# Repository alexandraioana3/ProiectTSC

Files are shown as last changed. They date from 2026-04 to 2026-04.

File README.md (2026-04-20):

==================================================
 PROIECT TSC 2026 - InkTime Smartwatch
==================================================
DINU ALEXANDRA - IOANA 332CC

1. DIAGRAMA BLOC

se afla in Diagrama-bloc.png

--------------------------------------------------
2. BILL OF MATERIALS (BOM)
--------------------------------------------------

Componenta      : MCU
Model           : Nordic nRF52840
Cod JLC         : C227306
Datasheet       : https://infocenter.nordicsemi.com/pdf/nRF52840_PS_v1.7.pdf

Componenta      : Charger
Model           : TI BQ25180
Cod JLC         : C5162464
Datasheet       : https://www.ti.com/lit/ds/symlink/bq25180.pdf

Componenta      : Fuel Gauge
Model           : Maxim MAX17048
Cod JLC         : C224357
Datasheet       : https://datasheets.maximintegrated.com/en/ds/MAX17048-MAX17049.pdf

Componenta      : Accelerometer
Model           : Bosch BMA421
Cod JLC         : C281864
Datasheet       : https://www.mouser.com/datasheet/2/783/bst-bma421-ds000-1509549.pdf

Componenta      : Haptic Driver
Model           : TI DRV2605L
Cod JLC         : C137152
Datasheet       : https://www.ti.com/lit/ds/symlink/drv2605l.pdf

Componenta      : Regulator
Model           : Richtek RT6160
Cod JLC         : C2892336
Datasheet       : https://www.richtek.com/assets/product_pdf/RT6160A/DS6160A-02.pdf

--------------------------------------------------
3. DESCRIERE FUNCTIONALITATE HARDWARE
--------------------------------------------------

[Sistemul de Putere]

- Incarcarea bateriei Li-Po se face prin BQ25180
- Monitorizare curent si temperatura integrata
- RT6160 stabilizeaza tensiunea la 3.3V
- Functionare posibila pana la ~2.8V baterie

[Senzori si Interfete]

- MAX17048:
  * Citire procent baterie prin I2C
  * Fara rezistenta externa de masura

- BMA421:
  * Detectie miscare
  * Step counting
  * Tilt-to-wake

- DRV2605L:
  * Control motor vibratii (ERM/LRA)
  * Efecte haptice integrate

- E-Paper Display:
  * Consum zero in stare statica
  * Control prin SPI

--------------------------------------------------
4. ALOCARE PINI nRF52840
--------------------------------------------------

USB D+ / D-  | USB Data     | USB-C (J5)
             |              | Pini dedicati pentru comunicatia USB nativa

P0.06        | I2C SDA      | Senzori / PMIC
             |              | Magistrala date (BMA421, MAX17048, BQ25180)

P0.07        | I2C SCL      | Senzori / PMIC
             |              | Magistrala clock pentru comunicatia I2C

P0.02        | SPI SCK      | E-Paper Display
             |              | Semnal de ceas pentru magistrala SPI

P0.03        | SPI MOSI     | E-Paper Display
             |              | Transmisie date imagine catre ecran

P0.05        | SPI CS       | E-Paper Display
             |              | Chip Select - activeaza comunicarea cu ecranul

P0.15        | EPD DC       | E-Paper Display
             |              | Data/Command control pentru driverul de ecran

P0.16        | EPD RST      | E-Paper Display
             |              | Reset hardware pentru panoul E-Paper

P0.17        | EPD BUSY     | E-Paper Display
             |              | Feedback de la ecran (procesare imagine)

P0.12        | HAPTIC EN    | DRV2605L
             |              | Activare / Trigger pentru driverul haptic

P0.11        | PMIC INT     | BQ25180
             |              | Intrerupere de la charger

P0.10        | ALERT        | MAX17048
             |              | Alerta baterie (ex: nivel critic)

P0.08        | IMU INT1     | BMA421
             |              | Intrerupere accelerometru (tap/tilt)

P1.08        | IMU INT2     | BMA421
             |              | Intrerupere secundara (low power)

P1.06        | BUTTON       | SW_UP
             |              | Buton navigare sus

P1.04        | BUTTON       | SW_DN
             |              | Buton navigare jos

P0.18        | RESET        | Debug Port
             |              | Reset hardware extern

SWDIO        | Debug Data   | TC2030 (J2)
             |              | Linie date programare

SWDCLK       | Debug Clock  | TC2030 (J2)
             |              | Linie ceas programare

P0.00 / 0.01 | XL1 / XL2    | Cristal 32kHz
             |              | Oscilator low power / RTC

XC1 / XC2    | HF Crystal   | Cristal 32MHz
             |              | Frecventa principala + BLE

VBUS         | Power Sense  | USB VBUS
             |              | Detectie 5V USB

VDDH         | High Voltage | 3.3V VCC
             |              | Alimentare principala

--------------------------------------------------
5. DESIGN LOG SI DECIZII
--------------------------------------------------

[Status: Finalizare Partiala]

- Overlap Errors (#16):
  * 65 erori acceptate
  * Cauza: densitate mare aQFN + PCB 2 straturi
  * Solutie viitoare: PCB 4 straturi

- Airwires (#15):
  * 16 conexiuni ramase
  * Nu afecteaza functionarea de baza
  * Evitare scurtcircuite in zone critice

- Antena RF:
  * Ground stitching aplicat
  * Keep-out respectat sub antena

- Vizualizare 3D:
  * PCB validat mecanic (1.0mm grosime)
  * Fara modele 3D componente

--------------------------------------------------
6. FISIERE DE FABRICATIE
--------------------------------------------------

Folder: /Manufacturing

Contine:

- Gerber Files (pentru productie PCB)
- BOM (lista componente)
- Pick and Place (asamblare SMT)

==================================================

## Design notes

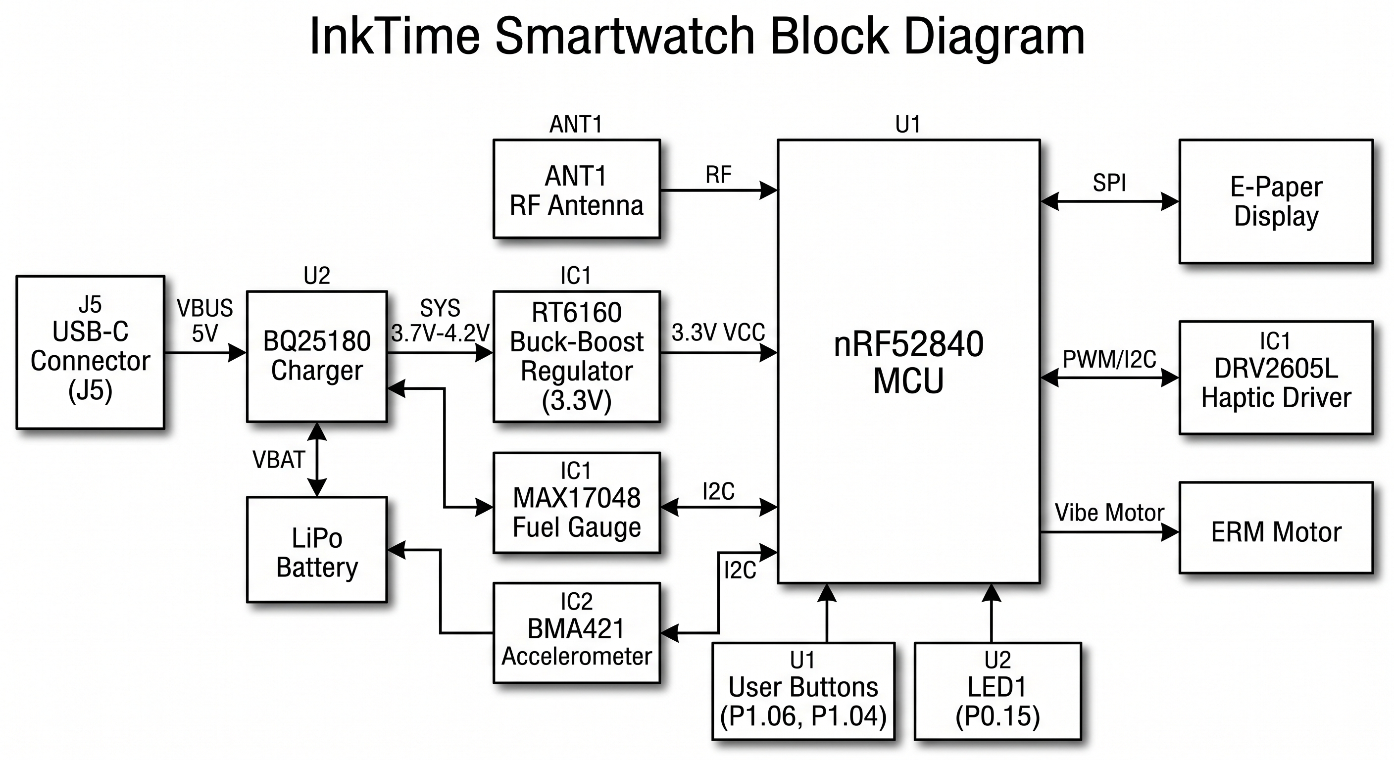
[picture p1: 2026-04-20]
Diagrama-Bloc.png

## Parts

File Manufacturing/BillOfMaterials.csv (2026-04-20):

Componenta | Producator/Model | Cod JLC Parts | Link Datasheet
MCU | Nordic nRF52840 | C227306 | https://infocenter.nordicsemi.com/pdf/nRF52840_PS_v1.7.pdf
Charger | TI BQ25180 | C5162464 | https://www.ti.com/lit/ds/symlink/bq25180.pdf
Fuel Gauge | Maxim MAX17048 | C224357 | https://datasheets.maximintegrated.com/en/ds/MAX17048-MAX17049.pdf
Accelerometer | Bosch BMA421 | C281864 | https://www.mouser.com/datasheet/2/783/bst-bma421-ds000-1509549.pdf
Haptic Driver | TI DRV2605L | C137152 | https://www.ti.com/lit/ds/symlink/drv2605l.pdf
Regulator | Richtek RT6160 | C2892336 | https://www.richtek.com/assets/product_pdf/RT6160A/DS6160A-02.pdf

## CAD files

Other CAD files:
Manufacturing/pcb-3d.f3d

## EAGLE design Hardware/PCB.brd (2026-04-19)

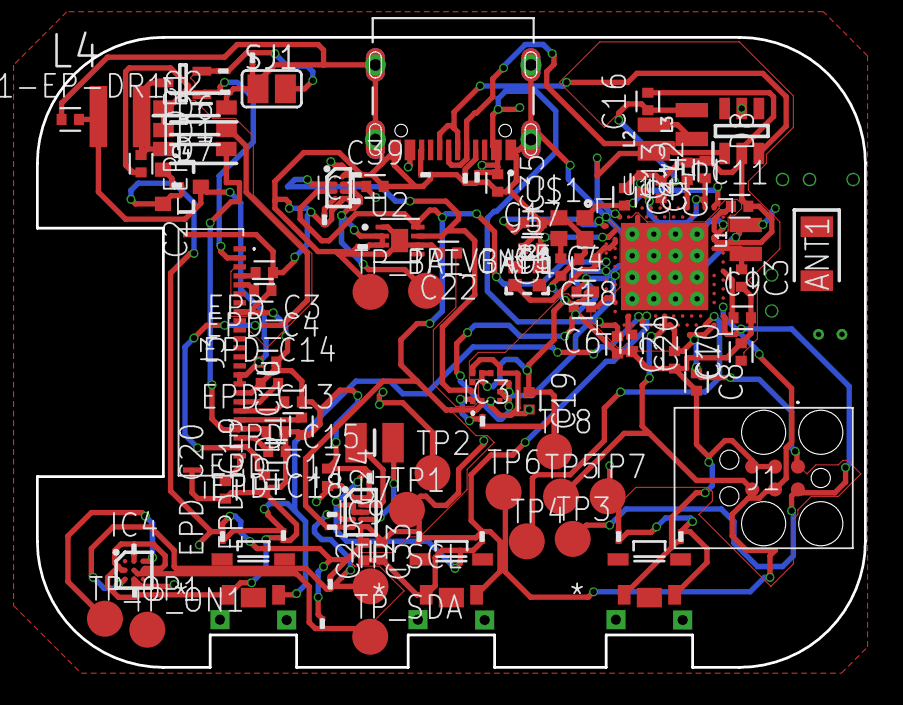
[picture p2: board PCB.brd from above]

Board: 4 copper layers, 46.0 x 35.0 mm, 105 parts (0 on the bottom side), 68 nets.

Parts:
ANT1: 2450AT18B100E; 2450AT18B100E_ANTC3216X140N
C1, C2, C17, C18: 12pF; CAPC1005X60
C1-EP-DR1, C24, C39: 10uF; CAPC1005X60
C2-EP-DR1: 4.7uF/25V; CAPC1005X60
C3, C4: 1pF; CAPC1005X60
C5, C7, C8, C12, C19: 100nF; CAPC1005X60
C6, C14, C20, C21: 4.7μF; CAPC1005X60
C9: 820pF N.C.; CAPC1005X60
C10, C13, C22: N.C.; CAPC1005X60
C11: 100pF; CAPC1005X60
C15: 1.0μF; CAPC1005X60
C16: 47nF; CAPC1005X60
C23, C26, C28, C36: 0.1uF; GRM011R60J152KE01L_1_0201
C25, C33: 22uF; CAPC1005X60
C35: 4.7uF; CAPC1005X60
C37, C38, C40, C41, C44, C45: 1uF; GRM011R60J152KE01L_1_0201
D1, D6, D7: MBR0530; ESP32_C6_LIBRARY_5_SOD3716X135N
D8: USBLC6-2SC6Y; ESP32_C6_LIBRARY_3_SOT95P280X145-6N
EPD_C3, EPD_C4, EPD_C14, EPD_C15, EPD_C16, EPD_C17, EPD_C18, EPD_C19, EPD_C20: 1uF/50V; CAPC1005X60
EPD_C13: 0.1uF/50V; CAPC1005X60
IC1: BQ25180YBGR; BQ25180YBGR_BGA8C40P2X4_100X155X50
IC3: BMA421; BMA423_BMA423
IC4: DRV2605YZFR; DRV2605YZFR_BGA9C50P3X3_144X144X62
IC9: RT6160AWSC; RT6160AWSC_BGA15C40P3X5_140X230X60
J1: TC2030-IDC_TC2030-IDC; TC2030-IDC_TC2030IDC
J3: 503480-2400; 503480-2400_5034802400
J5: KH-TYPE-C-16P; KH-TYPE-C-16P_KINGHELM_KH-TYPE-C-16P
L1: 3.9nH; 0805-WIDE
L2: 10μH; 0805-WIDE
L3: 15nH; 0805-WIDE
L4: 68uH; XFL4020
L7: FTC252012SR47MBCA; MLP2016SR47MT0S1_INDC2016X100N
Q2: SI1308EDL-T1-GE3; ESP32_C6_LIBRARY_6_SOT65P210X110-3N
Q4: 20V/4.2A/52mΩ/1.4W; ESP32_C6_LIBRARY_4_ESP32_C6_LIBRARY_4_ESP32_C6_LIBRARY_4_ES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
R1, R6, R10: 10k; CPF0201D7K68C1_0201
R1_EP_DR1: 0.47; CPF0201D7K68C1_0201
R1_USB1, R2_USB1: 5K1; CPF0201D7K68C1_0201
R2, R3, R4: 0; CPF0201D7K68C1_0201
R2_EP_DR1, R9: 10K; CPF0201D7K68C1_0201
R17, R18: 3K3; CPF0201D7K68C1_0201
R_PWR_EPD1: 10K; CPF0201D7K68C1_0201
R_TYPE_SEL1: 2.2; CPF0201D7K68C1_0201
SJ1: 0; ESP32_C6_LIBRARY_7_JUMPER_SJ
SW_DN: 2025-10-22_07-23-44_LIBRARY_EVP-AKE31ASW_EVP-AKE3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; 2025-10-22_07-23-44_LIBRARY_SW_EVP-AKE31A_PAN
SW_ENT: 2025-10-22_07-23-44_LIBRARY_EVP-AKE31ASW_EVP-AKE3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; 2025-10-22_07-23-44_LIBRARY_SW_EVP-AKE31A_PAN
SW_UP: 2025-10-22_07-23-44_LIBRARY_EVP-AKE31ASW_EVP-AKE3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; 2025-10-22_07-23-44_LIBRARY_SW_EVP-AKE31A_PAN
TP1, TP2, TP3, TP4, TP5, TP6, TP7, TP8: HECTOR_WATCH_1_TPTP20R; HECTOR_WATCH_1_TP20R
TP_BAT_GND1: HECTOR_WATCH_1_TPTP20R; HECTOR_WATCH_1_TP20R
TP_ON1: HECTOR_WATCH_1_TPTP20R; HECTOR_WATCH_1_TP20R
TP_OP1: HECTOR_WATCH_1_TPTP20R; HECTOR_WATCH_1_TP20R
TP_SCL: HECTOR_WATCH_1_TPTP20R; HECTOR_WATCH_1_TP20R
TP_SDA: HECTOR_WATCH_1_TPTP20R; HECTOR_WATCH_1_TP20R
TP_VBAT1: HECTOR_WATCH_1_TPTP20R; HECTOR_WATCH_1_TP20R
U1: NRF52840_QF; NORDIC_NRF_4_AQFN50P700X700X85_HS-74N
U2: MAX17048G+T10; ESP32_C6_LIBRARY_SON50P200X200X80-9N
U$1: NORDIC_NRF_BT-XTAL_2016_N
X2: 32MHz; CRYSTAL-SMD-2.0X1.6MM

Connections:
3V3: C6.1, C7.1, C8.1, C12.1, C14.2, C19.2, C25.2, C33.1, C36.2, IC3.3, IC3.7, IC3.10, IC4.C2, IC9.E2, IC9.E3, J1.1, Q4.2, R1.2, R6.2, R10.2, R17.1, R18.1, R_PWR_EPD1.2, TP1.TP, TP7.TP, U1.P$A22, U1.P$AD14, U1.P$AD23, U1.P$B1, U1.P$W1, U1.P$Y2
3V3/1.7D2: C40.2, IC4.A2
ALERT: U1.P$J24, U2.5
D+: D8.4, U1.P$AD6
D-: D8.6, U1.P$AD4
DEC1: C5.2, U1.P$C1
DEC3: C11.1, U1.P$D23
DEC4_6: C10.1, C15.2, C16.1, L3.2, U1.P$B5, U1.P$E24
DN: D8.1, J5.A7, J5.B7
DP: D8.3, J5.A6, J5.B6
EPD_3V3: C1-EP-DR1.2, EPD_C13.2, J3.15, J3.16, L4.P$1, Q4.3
EPD_BUSY: J3.9, U1.P$AD12
EPD_CS: J3.12, U1.P$K2
EPD_DC: J3.11, U1.P$AD10
EPD_RST: J3.10, U1.P$AC11
GDR: J3.2, Q2.1, R2_EP_DR1.2
GND: C1.1, C1-EP-DR1.1, C2.1, C3.2, C4.2, C5.1, C6.2, C7.2, C8.2, C9.2, C10.2, C11.2, C12.2, C13.2, C14.1, C15.1, C16.2, C17.1, C18.2, C19.1, C20.2, C21.2, C22.2, C23.2, C24.1, C25.1, C26.1, C28.2, C33.2, C35.2, C36.1, C37.1, C38.1, C39.2, C40.1, C41.1, C44.1, C45.1, D6.1, D8.2, EPD_C3.1, EPD_C4.1, EPD_C13.1, EPD_C14.1, EPD_C15.1, EPD_C16.1, EPD_C17.1, EPD_C18.1, EPD_C19.1, EPD_C20.1, IC1.D2, IC3.8, IC3.9, IC4.B1, IC4.B3, IC9.B1, IC9.C1, IC9.C2, IC9.C3, J1.3, J1.5, J3.8, J3.17, J3.MP1, J3.MP2, J5.A1_B12, J5.A12_B1, J5.SH1, J5.SH2, J5.SH3, J5.SH4, R1_USB1.1, R2_EP_DR1.1, R2_USB1.2, R3.1, R9.1, R_TYPE_SEL1.1, SJ1.1, SW_DN.1, SW_ENT.1, SW_UP.1, TP8.TP, TP_BAT_GND1.TP, U1.P$74, U1.P$75, U1.P$76, U1.P$77, U1.P$78, U1.P$79, U1.P$80, U1.P$81, U1.P$82, U1.P$83, U1.P$84, U1.P$85, U1.P$86, U1.P$87, U1.P$88, U1.P$89, U1.P$90, U1.P$B7, U1.P$F23, U2.1, U2.4, U2.6, U2.9, U$1.2, U$1.4
HAPTIC_EN: IC4.A1, U1.P$U1
IMU_INT1: IC3.5, U1.P$N1
IMU_INT2: IC3.6, U1.P$P2
LX1: IC9.B2, IC9.B3, L7.1
LX2: IC9.D2, IC9.D3, L7.2
MOSI: J3.14, U1.P$B13
unnamed: IC9.D1, R4.2
unnamed: IC9.E1, R2.2
unnamed: IC3.1, R3.2
unnamed: C3.1, L1.1, U1.P$H23
unnamed: ANT1.1, C4.1, C22.1, L1.2
unnamed: IC1.D1, R9.2
unnamed: C9.1, U1.P$N24
unnamed: C2-EP-DR1.1, D7.2, L4.P$2, Q2.3
unnamed: R1_EP_DR1.1, R_TYPE_SEL1.2, SJ1.2
unnamed: C2-EP-DR1.2, D1.1, D6.2
unnamed: EPD_C3.2, J3.4
unnamed: EPD_C4.2, J3.5
unnamed: EPD_C14.2, J3.18
unnamed: EPD_C15.2, J3.19
unnamed: EPD_C16.2, J3.20
unnamed: EPD_C18.2, J3.22
unnamed: EPD_C20.2, J3.24
unnamed: J5.A5, R1_USB1.2
unnamed: J5.B5, R2_USB1.1
unnamed: C20.1, U1.P$AC5
unnamed: L2.2, L3.1
unnamed: L2.1, U1.P$B3
unnamed: C13.1, U1.P$A18
unnamed: C2.2, U1.P$A23, U$1.3
unnamed: C1.2, U1.P$B24, U$1.1
OUT+: IC4.A3, TP_OP1.TP
P0.00/XL1: C17.2, U1.P$D2, X2.3
P0.01/XL2: C18.1, U1.P$F2, X2.1
P0.13: C41.2, R1.1, SW_UP.2, U1.P$AD8
P0.14: C44.2, R6.1, SW_ENT.2, U1.P$AC9
P1.01: Q4.1, R_PWR_EPD1.1, U1.P$Y23
P1.02: C45.2, R10.1, SW_DN.2, U1.P$W24
PREVGH: D7.1, EPD_C17.2, J3.21
PREVGL: D1.2, EPD_C19.2, J3.23
RESE: J3.3, Q2.2, R1_EP_DR1.2
RESET: J1.6, TP5.TP, U1.P$AC13
SCK: J3.13, U1.P$A12
SCL: IC1.B1, IC3.12, IC4.C1, R4.1, R17.2, TP_SCL.TP, U1.P$M2, U2.7
SDA: IC1.C1, IC3.2, IC4.B2, R2.1, R18.2, TP_SDA.TP, U1.P$L1, U2.8
SWDCLK: J1.4, TP6.TP, U1.P$AA24
SWDIO: J1.2, TP3.TP, U1.P$AC24
SWO: TP4.TP, U1.P$AD22
VBAT: C26.2, C37.2, IC1.C2, TP_VBAT1.TP, U2.2, U2.3
VBUS: C21.1, C28.1, C35.1, C38.2, D8.5, IC1.A2, J5.A4_B9, J5.A9_B4, U1.P$AD2
VREG: C23.1, C24.2, C39.1, IC1.B2, IC9.A1, IC9.A2, IC9.A3, TP2.TP

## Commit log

2026-04-10 EVT: initial schematic and folder structure
    [Schematic.sch]
2026-04-17 final PCB version
2026-04-17 PCB review fix
    [PCB.brd]
2026-04-19 fixing issues #14 and #12 in schematic
    [Schematic.sch]
2026-04-19 solve sugestion from issue #3
    [Schematic.sch]
2026-04-19 fixing issues #25 and partially #15 in pcb
    [PCB.brd]
2026-04-19 fixing issue #18 in pcb
    [PCB.brd]
2026-04-19 improve the bugs from issues #26 #16 #17 in pcb
    [PCB.brd]
2026-04-19 generate PCB 3D issue #27
    [pcb-3d.f3d]
2026-04-19 generate manufacturing files issue #28
    [PickNPlace.csv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]
2026-04-20 add readme #2
    [BillOfMaterials.csv]

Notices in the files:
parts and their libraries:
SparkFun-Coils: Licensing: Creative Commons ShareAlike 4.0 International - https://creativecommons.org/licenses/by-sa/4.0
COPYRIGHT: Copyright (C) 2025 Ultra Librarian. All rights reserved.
